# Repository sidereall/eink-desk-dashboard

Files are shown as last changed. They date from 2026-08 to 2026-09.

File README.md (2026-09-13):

# E-ink Desk Dashboard

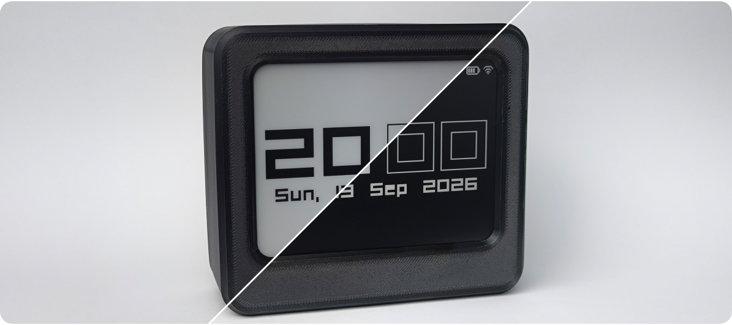
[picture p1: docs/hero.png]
E-ink desk dashboard


A standalone e-ink desk display built around an ESP32-C6 microcontroller, running firmware written in C++ with PlatformIO. It connects over Wi-Fi, syncs its time via NTP, and shows a clock, a task list, weather, and stock market data on a 4.2" e-ink panel, sourced from public APIs (Open-Meteo and Twelve Data). The device is configured entirely from a web page it serves over the local network.

---

## Screens

Four screens cycle on a timer, or one can be pinned, both configurable via the web page. Each shows the battery level and a Wi-Fi icon in the top right corner.

### Clock

Time from NTP, with the timezone chosen from the web page and daylight saving worked out automatically from it. The date line under the clock can be toggled on or off.

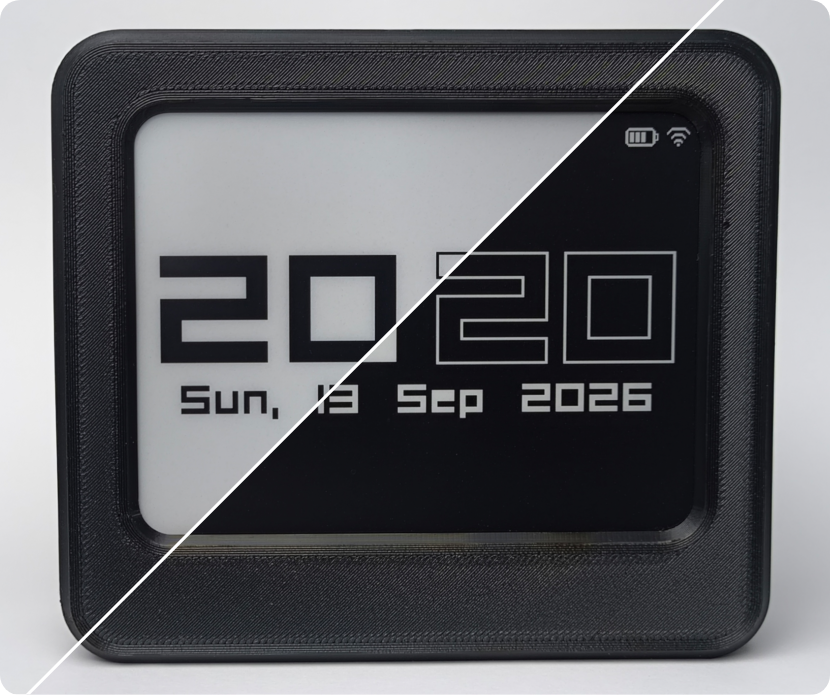
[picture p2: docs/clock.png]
Clock screen, light and dark


### Tasks

Five slots, edited from the web page. Shows the current date and how many entered tasks are complete. Completed tasks are struck through; deleting one closes the gap.

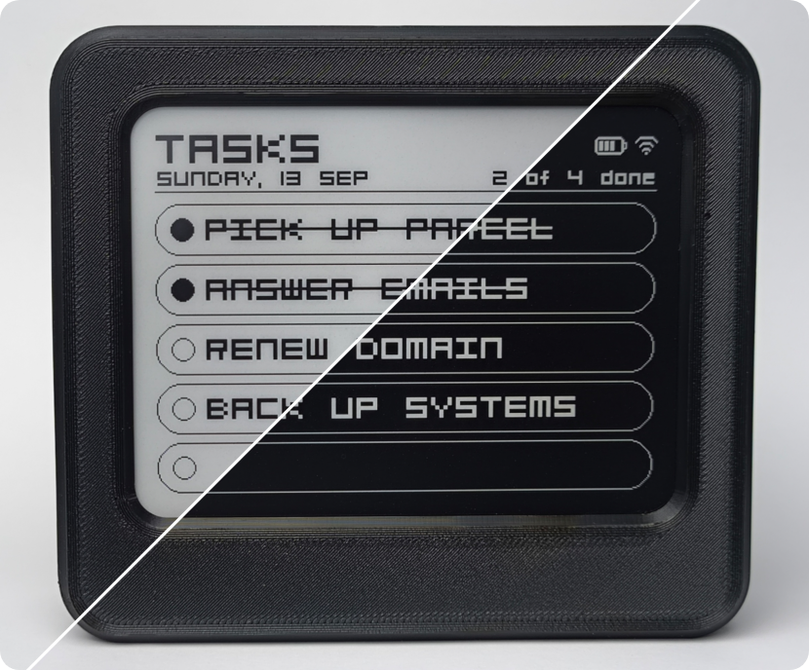
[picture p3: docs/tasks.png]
Tasks screen, light and dark


### Weather

Current conditions with a weather icon and today's high and low, plus a four-day forecast, from Open-Meteo. Location is searched by city name from the web page, along with a choice of Celsius or Fahrenheit. No API key needed.

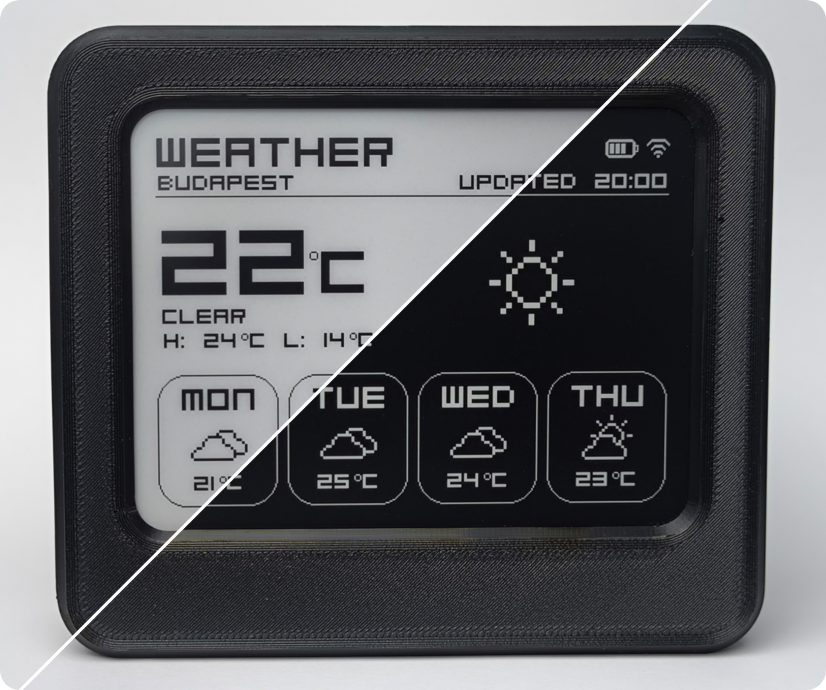
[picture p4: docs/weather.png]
Weather screen, light and dark


### Markets

A quote with the change since the previous close, and a sparkline of the session. The header shows whether the NYSE is open or closed. Any US stock or ETF can be chosen from the web page, searched by name or ticker, with SPY as the default. Needs a free Twelve Data key, also entered from the web page.

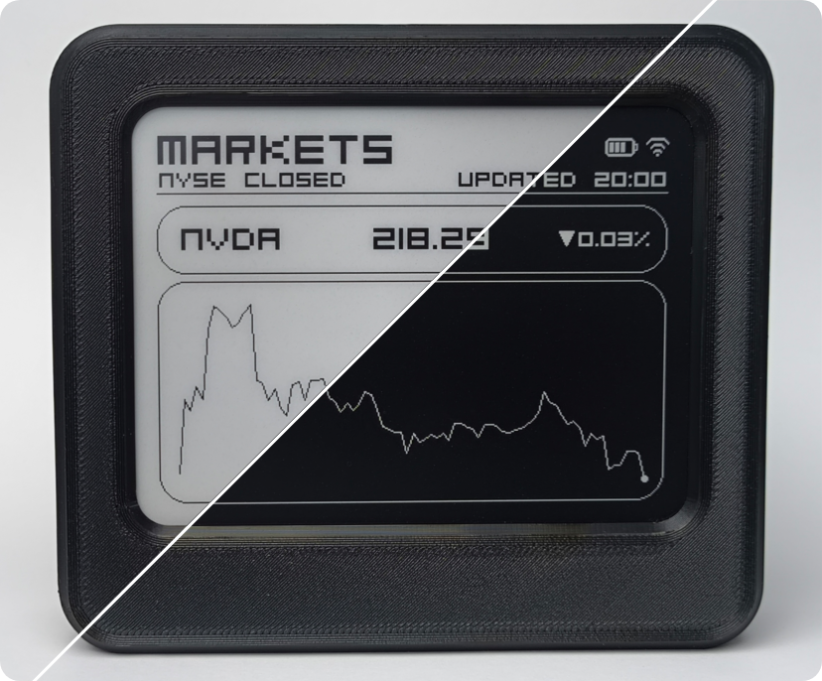
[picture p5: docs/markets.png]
Markets screen, light and dark


---

## Hardware

Roughly 30€ in parts including the enclosure.

| Part | Notes |
| --- | --- |
| ESP32-C6-DevKit | Any other C6 board should work without changes |
| WeAct 4.2" e-ink screen | 400x300, black and white, SSD1683 controller |
| SM5308 power module | USB-C input, charge and boost |
| 18650 li-ion cell | Used 2200mAh, size depends on desired runtime |
| 2x 82kΩ resistors | Voltage divider for the battery reading |
| 3D printed enclosure | Two .stl files modeled by me, see `enclosure/` |

<br>

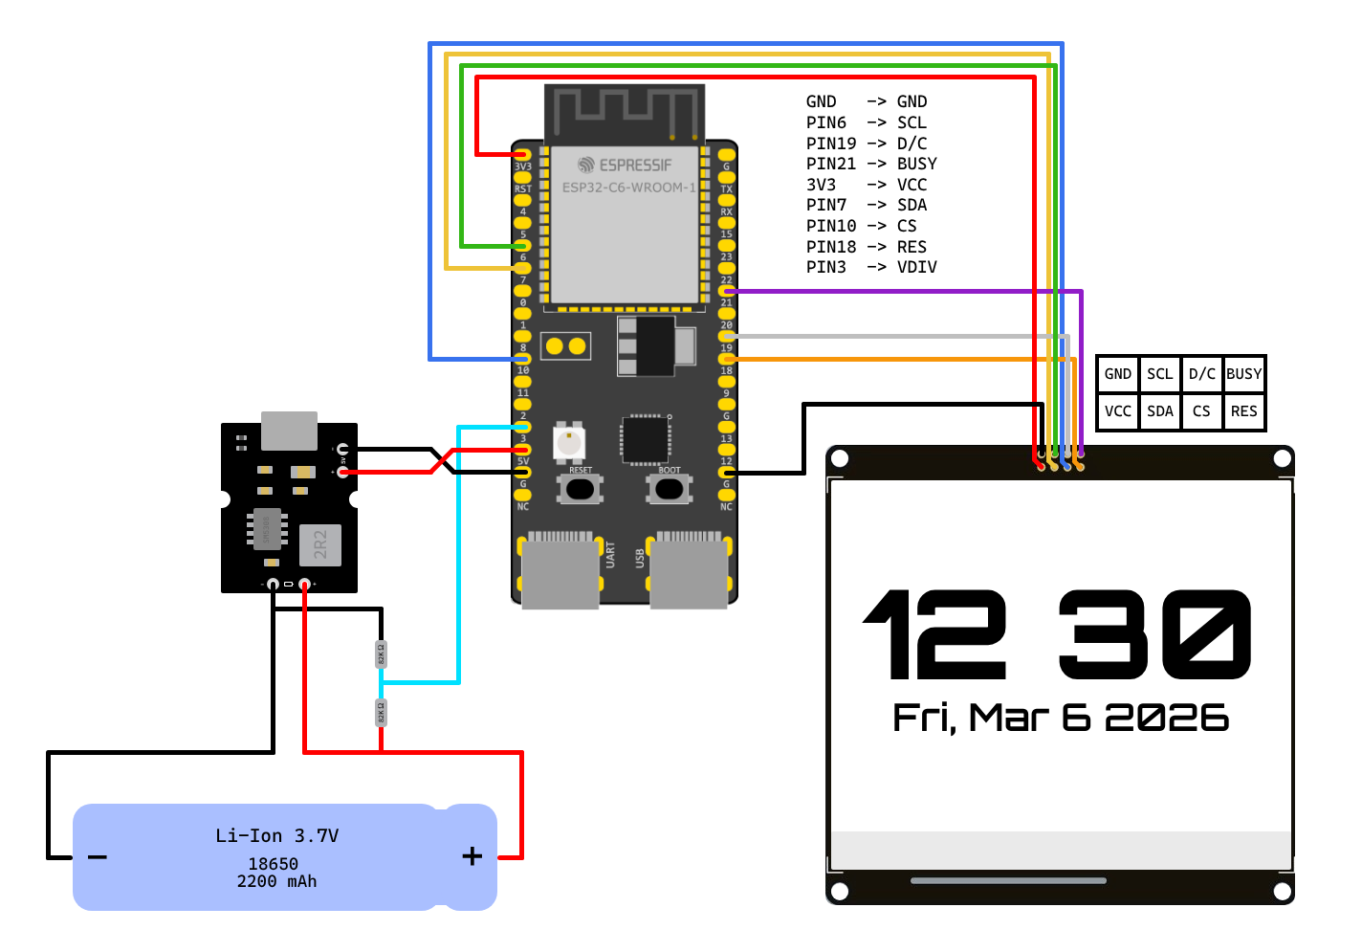
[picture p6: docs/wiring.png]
Wiring diagram

<br>
Assembled electronics

---

## Building

PlatformIO, with the [pioarduino](https://github.com/pioarduino/platform-espressif32) platform fork. The official PlatformIO only supports the ESP32C6 for ESP-IDF, but not yet for the Arduino framework this project uses.

```bash
git clone https://github.com/sidereall/eink-desk-dashboard
cd eink-desk-dashboard
cp src/secrets.h.example src/secrets.h    # then fill in your Wi-Fi details
```

Two uploads, since the firmware and the web page live in different places:

```bash
pio run -t upload      # firmware
pio run -t uploadfs    # the web page, onto the filesystem partition
```

Skipping the second step leaves the API working, but the config page returns a 404 error.

---

## Setting it up

After connecting to Wi-Fi, the panel shows its IP address. Opening that address in a browser on the same network loads the config page, which also shows the IP from then on.

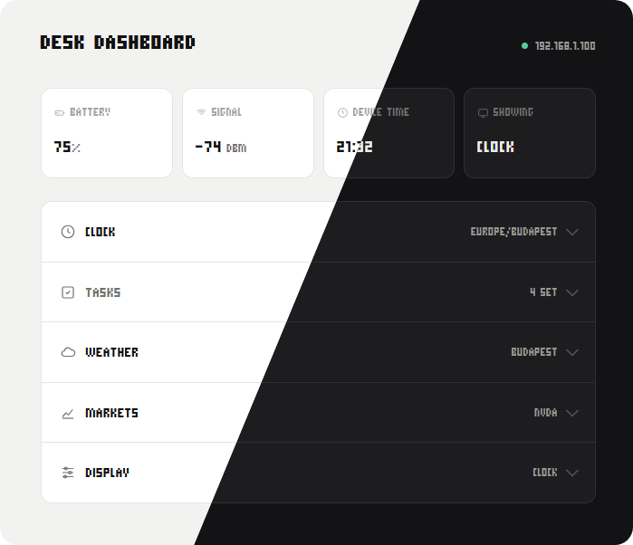
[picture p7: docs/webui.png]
The config page


A status strip along the top shows the battery level, signal strength, device time and which screen is currently up. Below it, each section can be expanded to change its settings, and shows what it's currently set to when collapsed:

- **Clock** - Time zone, and whether to show the date line.
- **Tasks** - The five task slots.
- **Weather** - Location, searched by city name, and Celsius or Fahrenheit.
- **Markets** - The Twelve Data API key, and a search for a US-listed stock or ETF.
- **Display** - Cycle through screens or pin one, the rotation interval, and dark mode.

Each section saves on its own, and the panel redraws immediately. The page reads the device's current settings on load, so opening it from a different browser shows what's already configured. Except the Twelve Data key, which only reports whether one is set.

Settings survive a power cut and a reflash. Holding BOOT for three seconds clears them.

---

## Project structure

```
src/
  main.cpp           |setup, the main loop, and everything that draws
  panel.cpp          |the only file that talks to the display driver
  screens.cpp        |draws each screen from a state struct
  clock_time.cpp     |NTP and the timezone rules
  tasks.cpp          |the task list, in RAM and saved to flash
  weather.cpp        |Open-Meteo fetch, on its own task
  markets.cpp        |Twelve Data fetch, on its own task
  wifi_net.cpp       |the connection and its reconnect handling
  web_ui.cpp         |the config page and its API
  app_settings.cpp   |everything that persists
  config.h           |every tunable number in the project
data/
  index.html         |the config page itself
```

---

## Security

**Protected.** Every write endpoint validates input at the boundary. Secrets never come back out: the markets key reads back only as configured or not, the Wi-Fi password exists only in the compiled firmware, and the key is logged by length alone. The radio won't join anything weaker than WPA2, so an open network with a matching name can't lure the device onto it.

**Not protected.** Any device on the same network can call the write endpoints, the same setup as most consumer devices on the LAN.

**Deliberately not done.** HTTPS would need a self-signed certificate and a browser warning on every visit, worse for the user than the problem it solves. Flash encryption is disproportionate for this scope.

---

## Future plans

- ~~Dark mode for both the panel and the web page.~~
- ~~Choice of any US stock or ETF for the markets screen, not just SPY.~~
- ~~Temperature unit switching, Celsius or Fahrenheit.~~
- ~~Battery charge level monitoring.~~
- ~~Web page UI/UX improvements.~~
- Fix bugs surfacing from longer-term use.
- Wi-Fi setup through a temporary access point, instead of compiling credentials in.
- Custom PCB, replacing the current point-to-point wiring.

---

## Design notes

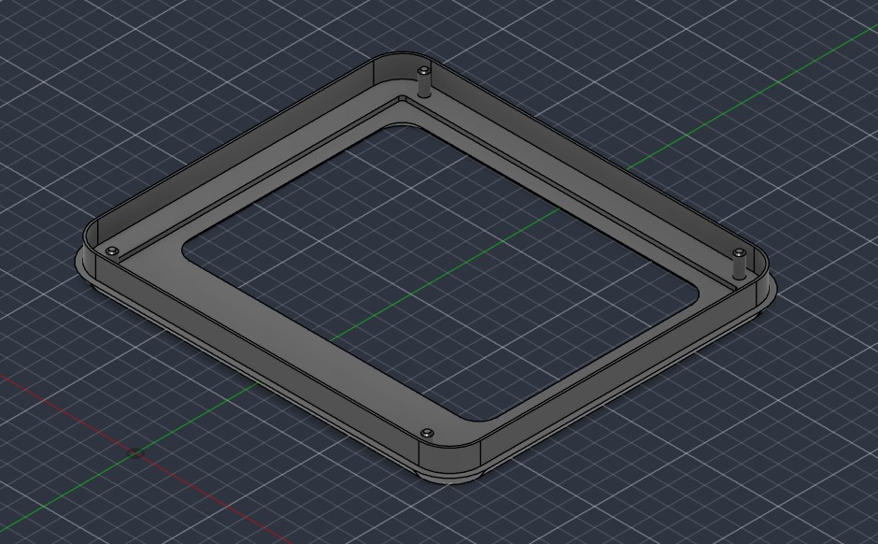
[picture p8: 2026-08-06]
enclosure/enclosure_screen.jpg

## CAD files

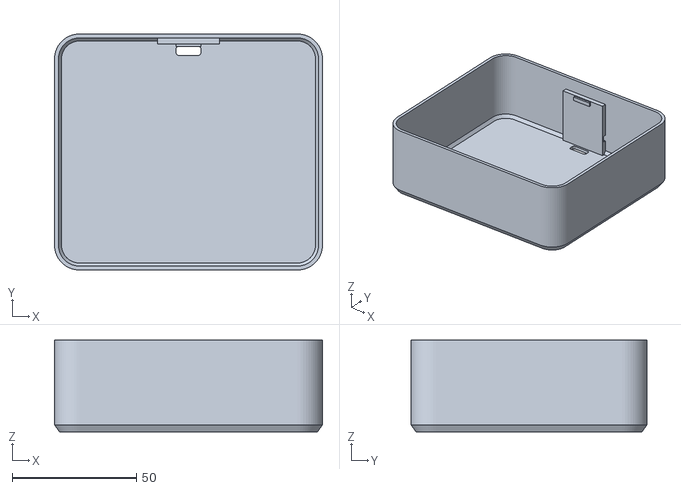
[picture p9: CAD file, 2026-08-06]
enclosure/enclosure_body.stl
108.0 x 95.1 x 37.0

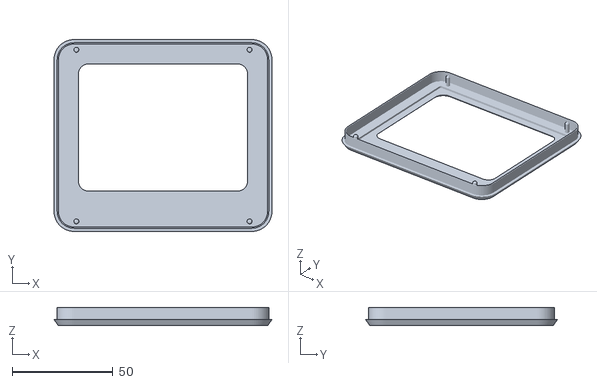
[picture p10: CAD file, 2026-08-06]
enclosure/enclosure_screen.stl
108.0 x 95.1 x 9.00

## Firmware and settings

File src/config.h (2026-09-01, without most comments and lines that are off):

#pragma once
#include <stddef.h>
#include <stdint.h>
#define CS_PIN 10
#define DC_PIN 19
#define RES_PIN 18
#define BUSY_PIN 21
#define SCK_PIN 6
#define MOSI_PIN 7
#define BUTTON_PIN 9
constexpr uint8_t BATTERY_PIN = 3;
constexpr float BATTERY_DIVIDER = 2.0f;
constexpr uint32_t BATTERY_POLL_MS = 60000;
constexpr uint8_t BATTERY_SAMPLES = 8; // a single read could swing by tens of mV
constexpr float BATTERY_MIN_VALID = 2.5f;
constexpr uint8_t BATTERY_UNKNOWN = 255;
constexpr float BATTERY_V_100 = 4.05f;
constexpr float BATTERY_V_75 = 3.90f;
constexpr float BATTERY_V_50 = 3.75f;
constexpr float BATTERY_V_25 = 3.60f;
constexpr int16_t ICON_BATT_W = 23;
constexpr int16_t ICON_BATT_H = 13;
constexpr int16_t HDR_BATT_X = 335;
constexpr int16_t HDR_BATT_Y = 23;
constexpr int16_t CLOCK_BATT_X = 345;
constexpr int16_t CLOCK_BATT_Y = 12;
constexpr int16_t SCREEN_W = 400;
constexpr int16_t SCREEN_H = 300;
constexpr uint16_t COL_BLACK = 0x0000;
constexpr uint16_t COL_WHITE = 0xFFFF;
extern uint16_t COL_FG;
extern uint16_t COL_BG;
constexpr uint8_t MAX_PARTIALS_BEFORE_FULL = 10;
enum DisplayMode : uint8_t {
  DISPLAY_CYCLE = 0,
  DISPLAY_STATIC = 1,
};
constexpr uint8_t DWELL_MIN_MINUTES = 5;
constexpr uint8_t DWELL_MAX_MINUTES = 60;
constexpr uint8_t DWELL_STEP_MINUTES = 5;
constexpr uint8_t DEFAULT_DWELL_MINUTES = 5;
constexpr uint8_t DEFAULT_DISPLAY_MODE = DISPLAY_CYCLE;
constexpr uint8_t DEFAULT_STATIC_SCREEN = 0; // clock
constexpr uint8_t SELECTABLE_SCREEN_COUNT = 4;
constexpr uint32_t CLOCK_POLL_MS = 500;
constexpr int16_t FRAME_RADIUS = 22;
constexpr int16_t HDR_TITLE_X = 21;
constexpr int16_t HDR_TITLE_Y = 37;
constexpr uint8_t HDR_TITLE_SIZE = 4;
constexpr int16_t HDR_SUB_X = 22;
constexpr int16_t HDR_SUB_Y = 55;
constexpr uint8_t HDR_SUB_SIZE = 2;
constexpr int16_t HDR_SUB_MAX_W = 201;
constexpr int16_t HDR_RULE_Y = 61;
constexpr int16_t HDR_RULE_X0 = 20;
constexpr int16_t HDR_RULE_X1 = 379;
constexpr int16_t HDR_WIFI_X = 364;
constexpr int16_t HDR_WIFI_Y = 21;
constexpr int16_t ICON_WIFI_W = 16;
constexpr int16_t ICON_WIFI_H = 16;
constexpr int16_t ICON_SMALL_W = 48;
constexpr int16_t ICON_SMALL_H = 48;
constexpr int16_t ICON_BIG_W = 96;
constexpr int16_t ICON_BIG_H = 96;
constexpr int16_t ICON_DEG_LARGE_W = 38;
constexpr int16_t ICON_DEG_LARGE_H = 30;
constexpr int16_t ICON_DEG_SMALL_W = 16;
constexpr int16_t ICON_DEG_SMALL_H = 10;
constexpr int16_t MSG_LINE1_Y = 150;
constexpr int16_t MSG_LINE2_Y = 185;
constexpr int16_t MSG_SINGLE_Y = 165;
constexpr uint8_t CLOCK_DIGIT_SIZE = 15;
constexpr int16_t CLOCK_DIGIT_Y = 160;
constexpr int16_t CLOCK_DIGIT_GAP = 30;
constexpr int8_t CLOCK_OUTLINE_PX = 2; // Hollow minute stroke width
constexpr uint8_t CLOCK_DATE_SIZE = 4;
constexpr int16_t CLOCK_DATE_Y = 207;
constexpr int16_t CLOCK_WIFI_X = 374;
constexpr int16_t CLOCK_WIFI_Y = 10;
constexpr int16_t CLOCK_NOSYNC_Y = 160;
constexpr int16_t CLOCK_TIME_BAND_X = 0;
constexpr int16_t CLOCK_TIME_BAND_Y = 60;
constexpr int16_t CLOCK_TIME_BAND_W = 400;
constexpr int16_t CLOCK_TIME_BAND_H = 124;
constexpr uint8_t MAX_TASKS = 5;
constexpr size_t TASK_TITLE_MAX = 48;
constexpr int16_t TASK_BOX_X = 20;
constexpr int16_t TASK_BOX_Y0 = 70;
constexpr int16_t TASK_BOX_W = 360;
constexpr int16_t TASK_BOX_H = 37;
constexpr int16_t TASK_BOX_RADIUS = 18;
constexpr int16_t TASK_ROW_PITCH = 43;
constexpr int16_t TASK_CHECK_CX = 39;
constexpr int16_t TASK_CHECK_DY = 18;
constexpr int16_t TASK_CHECK_R = 8;
constexpr int16_t TASK_TEXT_X = 56;
constexpr int16_t TASK_TEXT_DY = 23;
constexpr uint8_t TASK_TEXT_SIZE = 3;
constexpr int16_t TASK_TEXT_MAX_W = (TASK_BOX_X + TASK_BOX_W) - TASK_TEXT_X - 10;
constexpr int16_t TASK_STRIKE_OFFSET = 6;
constexpr int16_t TASK_STRIKE_THICK = 2;
constexpr int16_t TASK_COUNT_RIGHT = 378;
constexpr int16_t TASK_COUNT_Y = 55;
constexpr int16_t WX_UPDATED_RIGHT = 378;
constexpr int16_t WX_UPDATED_Y = 55;
constexpr uint8_t WX_TEMP_SIZE = 9;
constexpr int16_t WX_TEMP_X = 24;
constexpr int16_t WX_TEMP_Y = 121;
constexpr int16_t WX_DEG_LARGE_Y = 100;
constexpr int16_t WX_STATUS_X = 24;
constexpr int16_t WX_STATUS_Y = 148;
constexpr int16_t WX_HL_Y = 165;
constexpr int16_t WX_HIGH_X = 25;
constexpr int16_t WX_LOW_X = 109;
constexpr int16_t WX_HL_DEG_Y = 157;
constexpr int16_t WX_BIG_ICON_X = 234;
constexpr int16_t WX_BIG_ICON_Y = 77;
constexpr int16_t WX_CARD_X0 = 20;
constexpr int16_t WX_CARD_Y = 186;
constexpr int16_t WX_CARD_W = 85;
constexpr int16_t WX_CARD_H = 94;
constexpr int16_t WX_CARD_R = 20;
constexpr int16_t WX_CARD_PITCH = 92;
constexpr uint8_t WX_CARD_COUNT = 4;
constexpr int16_t WX_CARD_DAY_DX = 17;
constexpr int16_t WX_CARD_DAY_DY = 22;
constexpr int16_t WX_CARD_ICON_DX = 19;
constexpr int16_t WX_CARD_ICON_DY = 25;
constexpr int16_t WX_CARD_TEMP_DX = 22;
constexpr int16_t WX_CARD_TEMP_DY = 80;
constexpr int16_t WX_CARD_DEG_DY = 72;
constexpr int16_t WX_DEG_GAP = 4;
constexpr int16_t MK_UPDATED_RIGHT = 378;
constexpr int16_t MK_UPDATED_Y = 55;
constexpr int16_t MK_BOX_X = 20;
constexpr int16_t MK_BOX_Y = 70;
constexpr int16_t MK_BOX_W = 360;
constexpr int16_t MK_BOX_H = 48;
constexpr int16_t MK_BOX_R = 20;
constexpr uint8_t MK_NAME_SIZE = 3;
constexpr int16_t MK_NAME_X = 37;
constexpr int16_t MK_NAME_Y = 98;
constexpr int16_t MK_PRICE_X = 172;
constexpr int16_t MK_PRICE_Y = 98;
constexpr int16_t MK_TRI_CX = 308;
constexpr int16_t MK_TRI_TOP_Y = 88;
constexpr int16_t MK_TRI_BOT_Y = 98;
constexpr int16_t MK_TRI_HALF_W = 5;
constexpr int16_t MK_PCT_X = 317;
constexpr int16_t MK_PCT_Y = 97;
constexpr int16_t MK_CHART_X = 20;
constexpr int16_t MK_CHART_Y = 123;
constexpr int16_t MK_CHART_W = 360;
constexpr int16_t MK_CHART_H = 158;
constexpr int16_t MK_CHART_R = 20;
constexpr int16_t MK_SPARK_PAD_X = 14;
constexpr int16_t MK_SPARK_PAD_TOP = 16;
constexpr int16_t MK_SPARK_PAD_BOT = 16;
constexpr int16_t MK_MSG_Y = 210;
#define DEVICE_HOSTNAME "dashboard" // router DHCP name
#define NTP_SERVER_1 "pool.ntp.org"
#define NTP_SERVER_2 "time.nist.gov"
#define NTP_SERVER_3 "time.google.com"
#define DEFAULT_TZ_POSIX "UTC0"
#define DEFAULT_TZ_LABEL "UTC"
constexpr size_t TZ_POSIX_MAX = 48;
constexpr size_t TZ_LABEL_MAX = 40;
constexpr bool DEFAULT_FAHRENHEIT = false;
constexpr size_t WX_NAME_MAX = 24; // city name
constexpr uint8_t WEATHER_SLOT_MINUTES = 30;
constexpr uint16_t WEATHER_SLOT_OFFSET_SEC = 35;
constexpr int32_t FETCH_SLOT_MIN_GAP_SEC = 5;
constexpr uint32_t WEATHER_FETCH_MS = 30UL * 60 * 1000;
constexpr uint32_t WEATHER_RETRY_MS = 5UL * 60 * 1000;
constexpr uint32_t WEATHER_STALE_MS = 3UL * 60 * 60 * 1000; // if older than 3h, mark it
constexpr uint32_t WEATHER_HTTP_TIMEOUT_MS = 10000;
constexpr uint32_t WEATHER_TASK_STACK = 12288;
constexpr uint32_t FETCH_FIRST_DELAY_MS = 3000;
constexpr uint32_t FETCH_FIRST_STAGGER_MS = 1000; // markets after weather
constexpr uint32_t FETCH_NTP_GRACE_MS = 45000;
constexpr uint32_t SERIAL_BOOT_SETTLE_MS = 300;
#define DEFAULT_MARKET_SYMBOL "SPY"
constexpr size_t MARKET_SYMBOL_MAX = 12;
constexpr size_t MARKET_KEY_MAX = 40;
constexpr uint32_t MARKET_FETCH_MS = 30UL * 60 * 1000;
constexpr uint32_t MARKET_RETRY_MS = 5UL * 60 * 1000;
constexpr uint32_t MARKET_STALE_MS = 6UL * 60 * 60 * 1000; // if older than 6h, mark it
constexpr uint32_t MARKET_HTTP_TIMEOUT_MS = 10000;
constexpr uint32_t MARKET_TASK_STACK = 12288;
constexpr uint16_t MARKET_SLOT_OFFSET_SEC = 50;
constexpr uint32_t WIFI_RETRY_MIN_MS = 5000;
constexpr uint32_t WIFI_RETRY_MAX_MS = 60000;
constexpr uint32_t WIFI_STACK_RESET_MS = 300000; // 5 minutes
constexpr uint32_t NET_POLL_MS = 1000;
constexpr uint32_t BUTTON_DEBOUNCE_MS = 50;
constexpr uint32_t BUTTON_LONG_MS = 3000; // 3s hold -> reset
enum ButtonEvent : uint8_t { BTN_NONE = 0, BTN_SHORT, BTN_LONG };
constexpr bool INFO_ALWAYS_ON_BOOT = false;
constexpr int16_t INFO_IP_BOX_X = 20;
constexpr int16_t INFO_IP_BOX_Y = 70;
constexpr int16_t INFO_IP_BOX_W = 360;
constexpr int16_t INFO_IP_BOX_H = 48;
constexpr int16_t INFO_IP_BOX_R = 20;
constexpr int16_t INFO_IP_Y = 100;
constexpr uint8_t INFO_IP_SIZE = 3;
constexpr uint8_t INFO_ROW_COUNT = 6;  // ssid, security, signal, timezone, time, uptime
constexpr int16_t INFO_ROW_Y0 = 150;   // first row baseline
constexpr int16_t INFO_ROW_PITCH = 22; // row spacing
constexpr int16_t INFO_LABEL_X = 30;   // label column
constexpr int16_t INFO_VALUE_X = 150;  // value column
constexpr uint8_t INFO_ROW_SIZE = 2;
constexpr int16_t INFO_VALUE_MAX_W = (SCREEN_W - 20) - INFO_VALUE_X - 10; // clip before the frame

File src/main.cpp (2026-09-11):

// main.cpp - setup, the main loop, and everything that draws to the panel.
#include <Arduino.h>

#include "app_settings.h"
#include "clock_time.h"
#include "config.h"
#include "markets.h"
#include "panel.h"
#include "screens.h"
#include "tasks.h"
#include "weather.h"
#include "web_ui.h"
#include "wifi_net.h"

// Everything the screens draw from.
static AppState g_state;

// The current rotation screen. Never SCREEN_INFO, that's tracked separately.
static ScreenId g_screen = SCREEN_CLOCK;

static bool g_rotationEnabled[SCREEN_ROTATION_COUNT] = {
    /* CLOCK   */ true,
    /* TASKS   */ true,
    /* WEATHER */ true,
    /* MARKETS */ true,
};

// INFO takes over the panel until dismissed, then hands back to g_screen.
static bool g_showingInfo = false;

// Which minute INFO is showing, so it repaints on the boundary.
static uint32_t g_drawnInfoMinute = 0xFFFFFFFF;

static uint32_t g_lastScreenSwitch = 0;
static uint32_t g_lastNetPoll = 0;
static uint32_t g_lastClockPoll = 0;
static uint32_t g_lastBattPoll = 0;
static bool g_drawnSynced = false;

// Cached from NVS, re-read when the web page pushes a change.
static uint8_t g_displayMode = DEFAULT_DISPLAY_MODE;
static ScreenId g_staticScreen = (ScreenId)DEFAULT_STATIC_SCREEN;
static uint32_t g_dwellMs = (uint32_t)DEFAULT_DWELL_MINUTES * 60000UL;
static uint8_t g_drawnMinute = 255; // 255 = nothing drawn yet
static uint8_t g_drawnHour = 255;

// Whichever screen is on the panel right now, INFO included.
static ScreenId activeScreen() { return g_showingInfo ? SCREEN_INFO : g_screen; }

uint8_t webStatusBattery() { return g_state.batteryPct; }
ScreenId webStatusScreen() { return activeScreen(); }

// Passed to the panel, which calls it to draw a frame.
static void renderActive(Adafruit_GFX &g) { drawScreen(g, activeScreen(), g_state); }

// The frame guard: renders off-screen and hashes it, so a refresh only happens
// when the picture actually changes.
static GFXcanvas1 *g_probe = nullptr;
static uint32_t g_shownHash = 0;
static bool g_haveHash = false;

static uint32_t frameHash() {
  if (!g_probe)
    return 0;

  g_probe->fillScreen(0);
  drawScreen(*g_probe, activeScreen(), g_state);

  const uint8_t *buf = g_probe->getBuffer();
  const size_t n = (size_t)(SCREEN_W / 8) * SCREEN_H;

  uint32_t h = 2166136261u; // FNV-1a
  for (size_t i = 0; i < n; i++) {
    h ^= buf[i];
    h *= 16777619u;
  }
  return h;
}

// Full refresh, skipped if the frame is unchanged. Logs why it fired.
static void redrawFull(const char *reason) {
  // Cheap struct copies, keeps the stale flags current.
  weatherCopyInto(g_state);
  marketsCopyInto(g_state);

  const uint32_t h = frameHash();
  if (g_haveHash && h == g_shownHash) {
    Serial.printf("[panel] SKIPPED (%s) - the frame is already on screen\n", reason);
    g_drawnMinute = g_state.minute;
    g_drawnHour = g_state.hour;
    return;
  }

  Serial.printf("[panel] FULL refresh  <- %s\n", reason);
  panelDrawFull(renderActive);

  g_shownHash = h;
  g_haveHash = true;
  g_drawnMinute = g_state.minute;
  g_drawnHour = g_state.hour;
}

// A partial refresh changes the panel too, so the stored hash has to follow.
static void noteFrameShown() {
  g_shownHash = frameHash();
  g_haveHash = true;
}

// Reads the clock and the saved timezone into AppState.
static void copyTimeIntoState() {
  char posix[TZ_POSIX_MAX];
  settingsGetTz(posix, sizeof(posix), g_state.tzLabel, sizeof(g_state.tzLabel));
  g_state.showDate = settingsShowDate();

  struct tm t;
  if (!clockGetLocal(t)) {
    // No RTC, so a cold boot doesn't know the time.
    g_state.timeSynced = false;
    g_state.hour = 0;
    g_state.minute = 0;
    snprintf(g_state.clockDate, sizeof(g_state.clockDate), "%s", "WAITING FOR NTP");
    snprintf(g_state.tasksDate, sizeof(g_state.tasksDate), "%s", "WAITING FOR NTP");
    return;
  }

  g_state.timeSynced = true;
  g_state.hour = (uint8_t)t.tm_hour;
  g_state.minute = (uint8_t)t.tm_min;
  clockFormatDate(t, g_state.clockDate, sizeof(g_state.clockDate));
  clockFormatDateLong(t, g_state.tasksDate, sizeof(g_state.tasksDate));
}

// Reads the live radio state into AppState.
static void copyNetworkIntoState() {
  WifiStatus w;
  wifiGetStatus(w);

  g_state.wifiConnected = w.connected;
  g_state.rssi = w.rssi;
  g_state.uptimeSec = millis() / 1000UL;
  snprintf(g_state.ip, sizeof(g_state.ip), "%s", w.ip);
  snprintf(g_state.ssid, sizeof(g_state.ssid), "%s", w.ssid);
  snprintf(g_state.security, sizeof(g_state.security), "%s", w.security);
}

// Re-reads the display settings from NVS into the cached globals.
static void reloadDisplaySettings() {
  g_displayMode = settingsDisplayMode();
  g_staticScreen = (ScreenId)settingsStaticScreen();
  g_dwellMs = (uint32_t)settingsDwellMinutes() * 60000UL;
  g_state.darkMode = settingsDarkMode();

  if (g_displayMode == DISPLAY_STATIC)
    g_screen = g_staticScreen;

  Serial.printf("[display] %s, screen=%s, dwell=%umin\n", (g_displayMode == DISPLAY_STATIC) ? "static" : "cycle",
                screenName(g_staticScreen), (unsigned)(g_dwellMs / 60000UL));
}

// How many screens are in the rotation.
static uint8_t rotationCount() {
  uint8_t n = 0;
  for (uint8_t i = 0; i < SCREEN_ROTATION_COUNT; i++) {
    if (g_rotationEnabled[i])
      n++;
  }
  return n;
}

// Advances to the next enabled screen and redraws.
static void goToNextRotationScreen() {
  for (uint8_t step = 1; step <= SCREEN_ROTATION_COUNT; step++) {
    const ScreenId candidate = (ScreenId)((g_screen + step) % SCREEN_ROTATION_COUNT);
    if (g_rotationEnabled[candidate]) {
      g_screen = candidate;
      break;
    }
  }
  g_showingInfo = false;
  redrawFull("rotated to a new screen");
  g_lastScreenSwitch = millis();
}

// Before NTP the clock minute is stuck at 0, so fall back to uptime.
static uint32_t infoMinute() { return g_state.timeSynced ? (uint32_t)g_state.minute : (millis() / 60000UL); }

static void showInfoScreen() {
  copyNetworkIntoState();
  g_showingInfo = true;
  g_drawnInfoMinute = infoMinute();
  redrawFull("info screen shown");
}

static void leaveInfoScreen() {
  // Dismissing is the acknowledgement, so the flag is only written now.
  settingsMarkInfoShown();

  g_showingInfo = false;
  redrawFull("left the info screen");
  g_lastScreenSwitch = millis();
}

// Short press = next screen, 3 second hold = reset.
static ButtonEvent pollButton() {
  static bool down = false;
  static bool raw = false;
  static uint32_t changedAt = 0;
  static uint32_t downAt = 0;
  static bool longFired = false;

  const bool now = (digitalRead(BUTTON_PIN) == LOW);
  if (now != raw) {
    raw = now;
    changedAt = millis();
  }

  // Keep the last value until the pin has been stable long enough.
  const bool debounced = (millis() - changedAt > BUTTON_DEBOUNCE_MS) ? raw : down;

  if (debounced && !down) { // pressed
    down = true;
    downAt = millis();
    longFired = false;
  } else if (debounced && down) { // still held
    if (!longFired && millis() - downAt >= BUTTON_LONG_MS) {
      longFired = true; // fire the instant 3s is reached
      return BTN_LONG;
    }
  } else if (!debounced && down) { // released
    down = false;
    if (!longFired)
      return BTN_SHORT; // short press fires on release
  }

  return BTN_NONE;
}

// Averaged, since a single ADC read swings by tens of millivolts. Li-ion
// doesn't fall linearly, so these steps are uneven.
static uint8_t batteryLevel() {
  uint32_t sum = 0;
  for (uint8_t i = 0; i < 8; i++) {
    sum += analogReadMilliVolts(BATTERY_PIN);
  }

  const float v = (sum / 8.0f / 1000.0f) * BATTERY_DIVIDER;

  if (v >= 4.05f)
    return 100;
  if (v >= 3.90f)
    return 75;
  if (v >= 3.75f)
    return 50;
  if (v >= 3.60f)
    return 25;
  return 0;
}

void setup() {
  Serial.begin(115200);
  delay(SERIAL_BOOT_SETTLE_MS); // let the USB host attach before printing
  Serial.println("\nDesk Dashboard ");

  pinMode(BUTTON_PIN, INPUT_PULLUP);
  settingsBegin();
  tasksBegin();
  weatherBegin();
  marketsBegin();
  clockBegin(); // applies the saved timezone before anything renders
  reloadDisplaySettings();

  copyTimeIntoState();
  tasksCopyInto(g_state);
  weatherCopyInto(g_state);

  // 15KB for the frame guard's canvas.
  g_probe = new GFXcanvas1(SCREEN_W, SCREEN_H);
  if (!g_probe || !g_probe->getBuffer()) {
    Serial.println("[panel] no memory for the frame guard - every redraw will run");
    g_probe = nullptr;
  }

  panelBegin();

  // Doesn't wait for Wi-Fi. With no connection the clock still draws.
  wifiBegin();
  copyNetworkIntoState();

  g_state.batteryPct = BATTERY_UNKNOWN;
  g_lastBattPoll = millis() - BATTERY_POLL_MS + 5000;

  if (!g_rotationEnabled[g_screen]) {
    for (uint8_t i = 0; i < SCREEN_ROTATION_COUNT; i++) {
      if (g_rotationEnabled[i]) {
        g_screen = (ScreenId)i;
        break;
      }
    }
  }

  // INFO on the first boot only. A 3 second BOOT hold brings it back.
  if (INFO_ALWAYS_ON_BOOT || !settingsInfoShown()) {
    showInfoScreen();
  } else {
    redrawFull("boot");
  }
  g_lastScreenSwitch = millis();
}

void loop() {
  wifiService();
  webService(); // same thread as the draws

  if (millis() - g_lastClockPoll >= CLOCK_POLL_MS) {
    g_lastClockPoll = millis();
    copyTimeIntoState();
  }

  if (millis() - g_lastBattPoll >= BATTERY_POLL_MS) {
    g_lastBattPoll = millis();
    const uint8_t was = g_state.batteryPct;
    g_state.batteryPct = batteryLevel();

    if (g_state.batteryPct != was) {
      redrawFull("battery level changed");
      return;
    }
  }

  // Wi-Fi came up or dropped
  if (millis() - g_lastNetPoll >= NET_POLL_MS) {
    g_lastNetPoll = millis();

    const bool was = g_state.wifiConnected;
    copyNetworkIntoState();

    if (g_state.wifiConnected != was) {
      if (g_state.wifiConnected) {
        Serial.printf("[net] up: %s  %s  %d dBm\n", g_state.ip, g_state.security, (int)g_state.rssi);
        webBegin();
        clockStartSync();      // NTP needs a network
        weatherRequestFetch(); // Weather needs network
        marketsRequestFetch(); // Quote needs network
      } else {
        Serial.println("[net] down");
        webStop();
      }

      // Only the icon changed, so repaint just its area. On INFO that area is
      // the whole screen, since every field there is network state.
      const Rect r = wifiDirtyRect(activeScreen());
      panelDrawPartial(r.x, r.y, r.w, r.h, renderActive);
      noteFrameShown();
      g_drawnInfoMinute = infoMinute();
      return;
    }
  }

  // A Save button on the web page. Already saved, so just reload and redraw.
  if (webTakeSyncRequest()) {
    Serial.println("[web] settings synced to the panel");
    reloadDisplaySettings();
    copyTimeIntoState();
    tasksCopyInto(g_state);
    redrawFull("web page pushed new settings");
    g_lastScreenSwitch = millis();
    return;
  }

  // Fresh data. Only repaint if that screen is the one showing.
  if (weatherTakeUpdate()) {
    weatherCopyInto(g_state);
    if (activeScreen() == SCREEN_WEATHER) {
      redrawFull("fresh weather data landed");
      return;
    }
  }

  if (marketsTakeUpdate()) {
    marketsCopyInto(g_state);
    if (activeScreen() == SCREEN_MARKETS) {
      redrawFull("fresh market data landed");
      return;
    }
  }

  if (webTakeDismissRequest() && g_showingInfo) {
    Serial.println("[web] info screen dismissed");
    leaveInfoScreen();
    return;
  }

  switch (pollButton()) {
  case BTN_LONG:
    // Wipes everything and shows INFO again, as if it were new.
    Serial.println("[btn] long press - factory reset");
    settingsFactoryReset();  // timezone, date toggle, display mode, weather, location, info flag
    tasksReset();            // task list
    clockBegin();            // re-reads the (now default) timezone: UTC
    weatherApplySettings();  // location is gone -> back to "SET A LOCATION"
    marketsApplySettings();  // key is gone -> back to "SET API KEY"
    reloadDisplaySettings(); // back to cycling, 5 minutes
    copyTimeIntoState();
    tasksCopyInto(g_state);
    showInfoScreen();
    return;
  case BTN_SHORT:
    if (g_showingInfo)
      leaveInfoScreen();
    else
      goToNextRotationScreen();
    return;
  default:
    break;
  }

  // INFO doesn't time out. It repaints once a minute to keep TIME and UPTIME
  // live, full screen but partial, so there's no flash.
  if (g_showingInfo) {
    if (infoMinute() != g_drawnInfoMinute) {
      g_drawnInfoMinute = infoMinute();
      copyNetworkIntoState(); // signal, uptime
      panelDrawPartial(0, 0, SCREEN_W, SCREEN_H, renderActive);
      noteFrameShown();
    }
    delay(20);
    return;
  }

  // Static mode never auto-advances, though a short press still steps through.
  if (g_displayMode == DISPLAY_CYCLE && rotationCount() > 1 && millis() - g_lastScreenSwitch >= g_dwellMs) {
    goToNextRotationScreen();
    return;
  }

  // NTP landed, so the whole clock screen changes at once.
  if (g_state.timeSynced != g_drawnSynced) {
    g_drawnSynced = g_state.timeSynced;
    Serial.printf("[clock] %s\n", g_state.timeSynced ? "synced" : "lost sync");
    redrawFull("NTP sync state changed");
    return;
  }

  if (g_screen == SCREEN_CLOCK) {
    if (g_state.hour != g_drawnHour) {
      // The date is outside the digit band, so this needs the whole screen.
      redrawFull("hour rolled over");
    } else if (g_state.minute != g_drawnMinute) {
      panelDrawPartial(CLOCK_TIME_BAND_X, CLOCK_TIME_BAND_Y, CLOCK_TIME_BAND_W, CLOCK_TIME_BAND_H,
                       renderActive); // digits only, no flash
      noteFrameShown();
      g_drawnMinute = g_state.minute;
    }
  }

  delay(20);
}

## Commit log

2026-08-07 fix(clock): centered digits with consistent spacing
    [config.h, screens.cpp]
2026-08-08 perf(wifi): enable modem sleep, 90mA -> 50mA
    Increases battery runtime with only slight added latency.
2026-08-10 feat(display): invert panel colors in dark mode, add toggle to webpage
    [app_settings.cpp, config.h, main.cpp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]
2026-08-11 fix(weather): dynamic degree glyph position after temperature
    [config.h, screens.cpp]
2026-08-13 style(web): change checkboxes to toggle switches in clock and display sections
2026-08-13 fix(display): right-align the updated time and task counter
    [config.h, screens.cpp]
2026-09-01 feat(battery): add battery level icons, read via a voltage divider
2026-09-01 docs(readme): document the battery indicator and update future plans section
